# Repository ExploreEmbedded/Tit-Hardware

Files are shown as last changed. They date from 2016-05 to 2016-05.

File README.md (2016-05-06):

# Tit-Hardware
Hardware design files for Tit with Atmega328pb 

Ever wanted to have two hardware Serial Ports, two SPI, two I2C and more PWM pins on the Arduino Pro Mini? Tit has all of this, and retains the same form factor. Tit uses Atmega328PB at its core. 

Tit, is pin compatible with Arduino Pro Mini, the chip Atmega328pb is software compatible with Atmega328p. Hence all the existing code and libraries should work without any changes. Tit uses higher version of avr-gcc toolchain, we have bundled it up as a package along with additional libraries required to access the extra features. Check the setup section on installing support for the board in the Arduino IDE.

Tit

Follow the project at hackaday.io
(https://hackaday.io/project/11558-tit)
Detailed introduction and setup guide at ExploreEmbedded.com
(http://exploreembedded.com/wiki/Tit,_a_supercharged_Arduino_Pro_Mini_with_Atmega328pb)

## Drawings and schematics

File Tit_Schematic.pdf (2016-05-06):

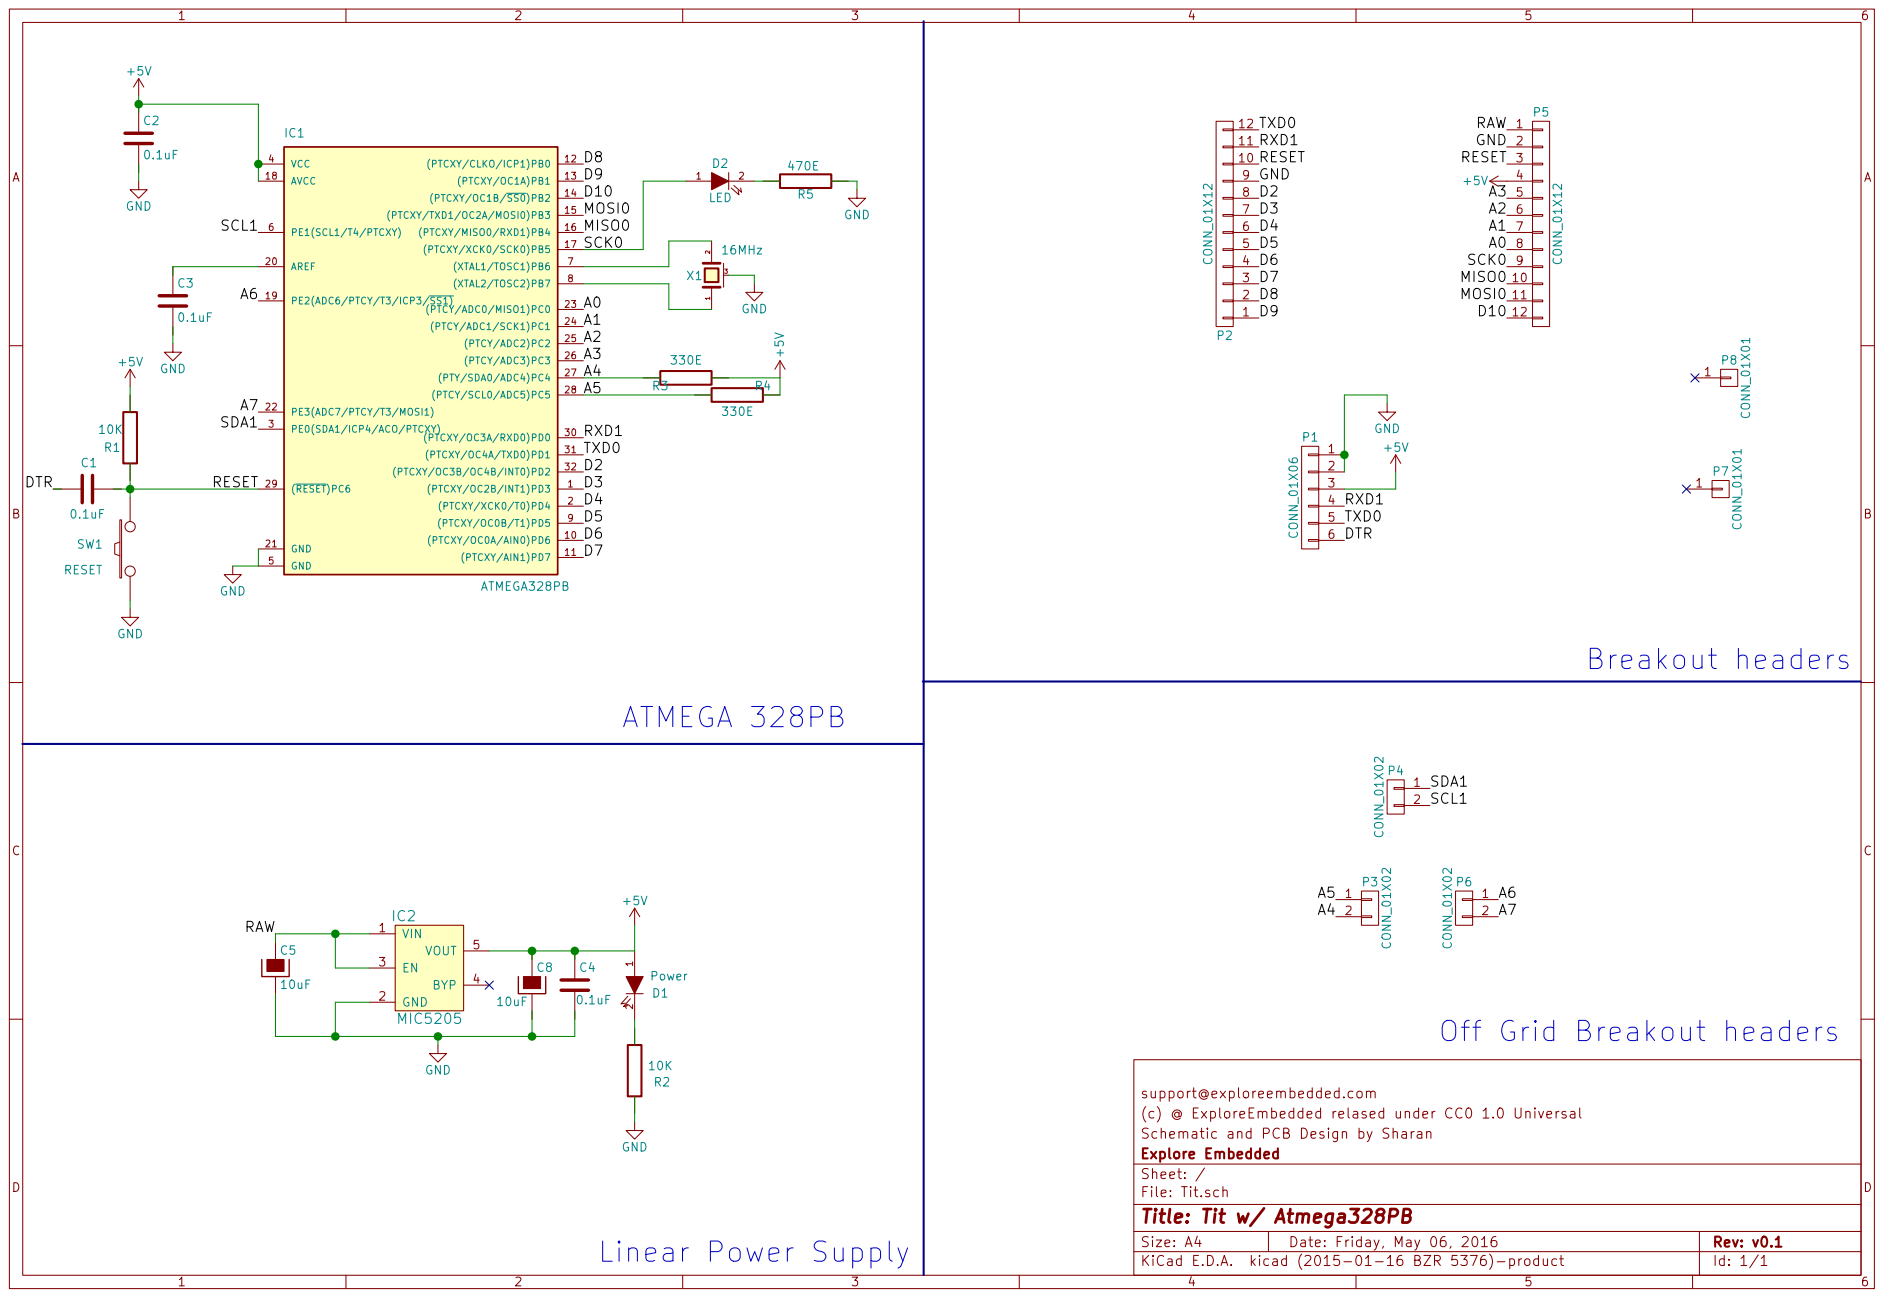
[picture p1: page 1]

support@exploreembedded.com
(c) @ ExploreEmbedded relased under CC0 1.0 Universal
Schematic and PCB Design by Sharan
File: Tit.sch Sheet: / Explore Embedded

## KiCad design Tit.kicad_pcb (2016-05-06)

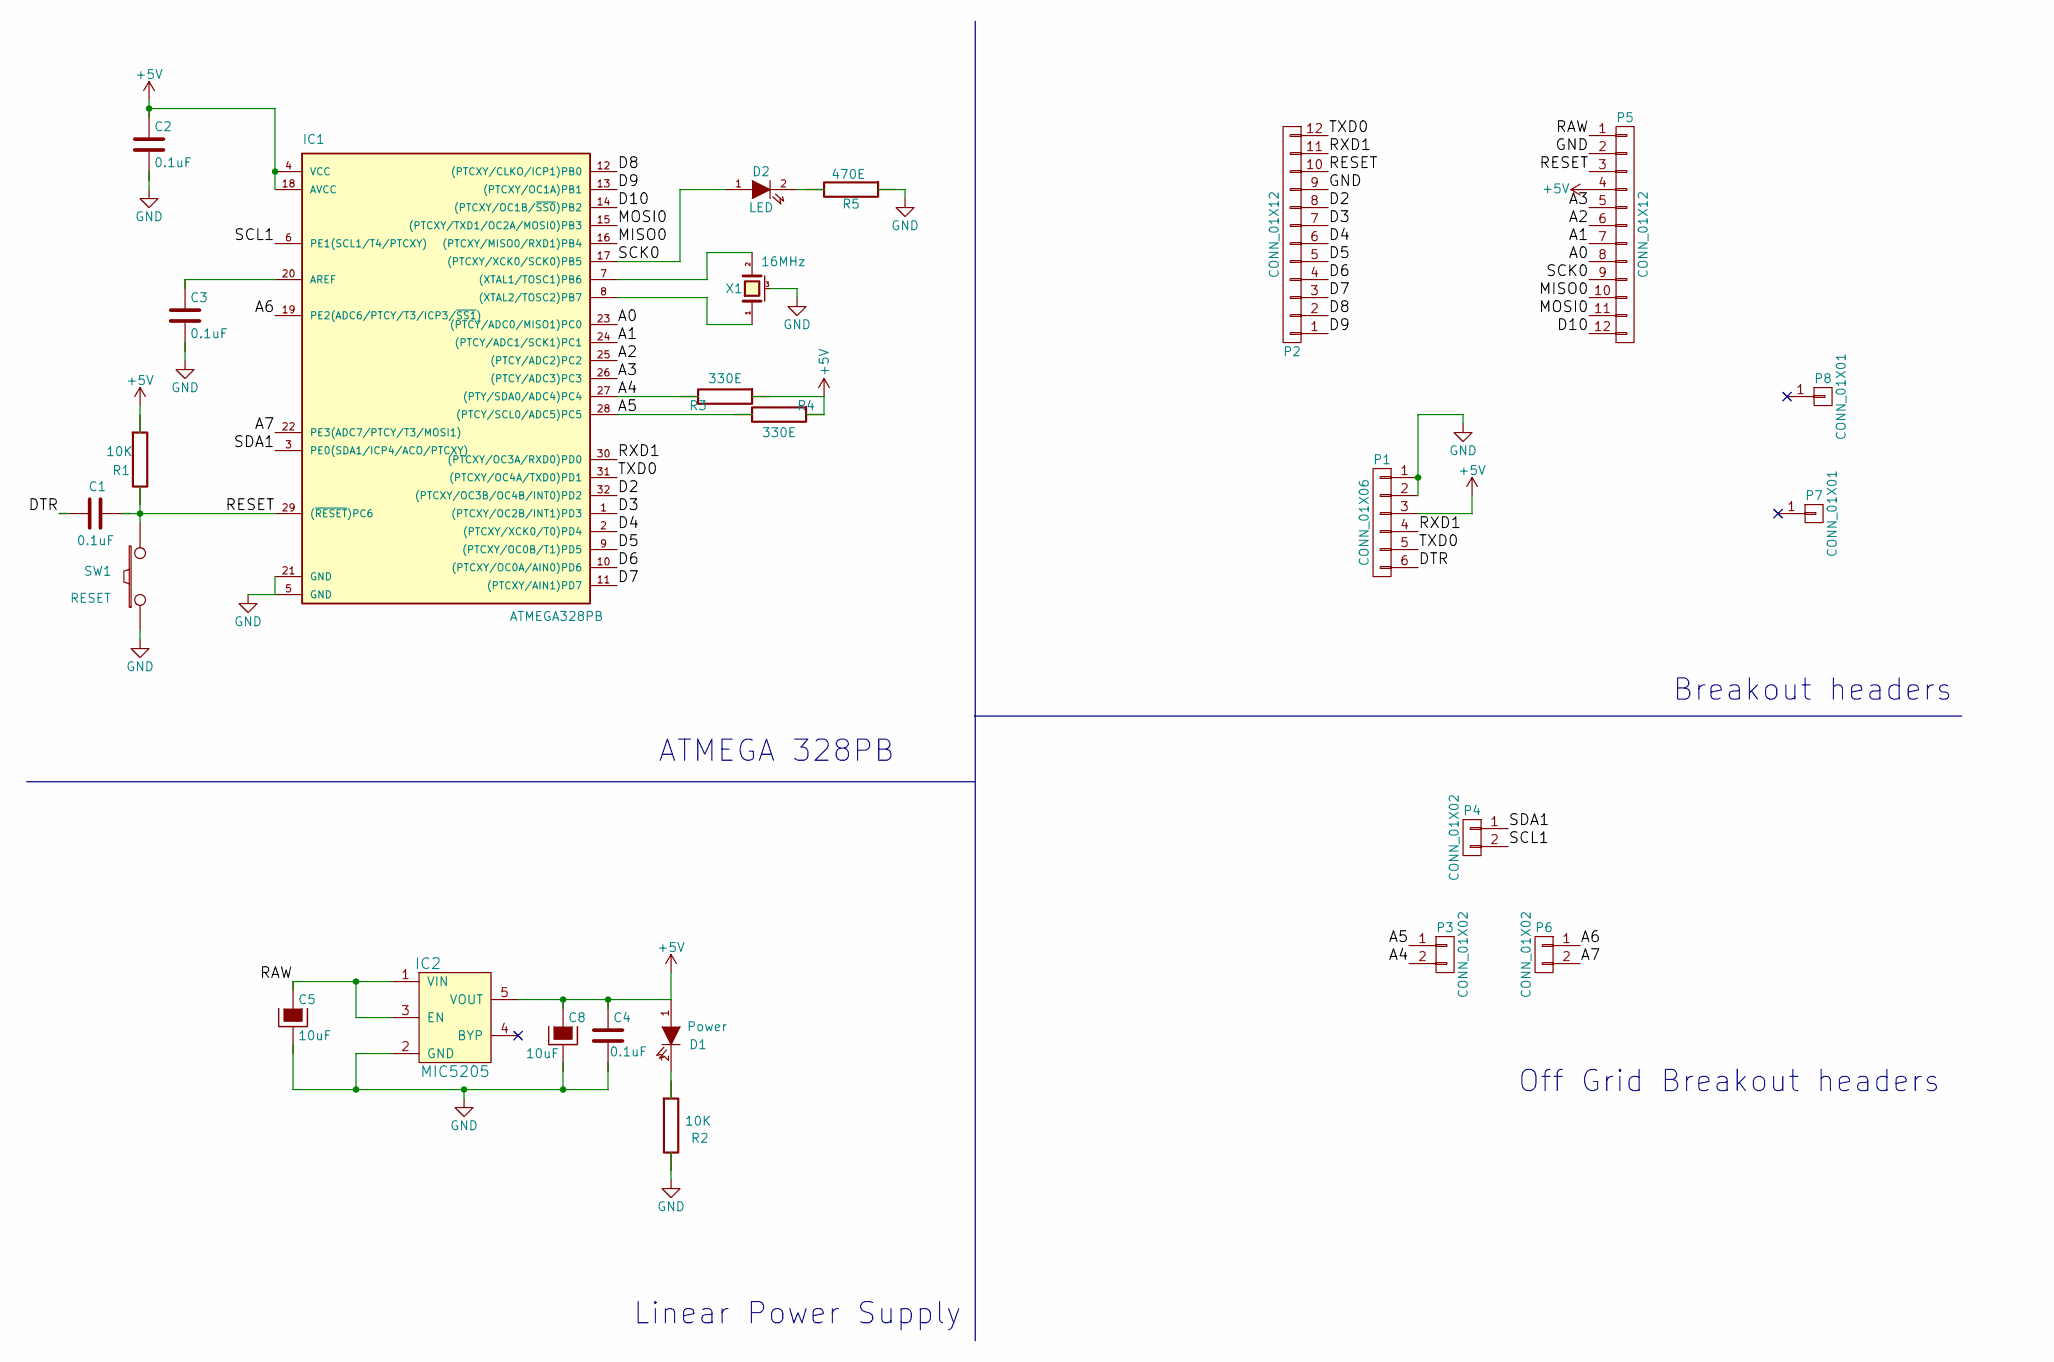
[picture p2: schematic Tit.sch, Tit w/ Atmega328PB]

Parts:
C1, C2, C3, C4: 0.1uF; C_0603
C5, C8: 10uF; C_1206
D1: Power; LED-0603
D2: LED; LED-0603
IC1: ATMEGA328PB; TQFP-32_7x7mm_Pitch0.8mm
IC2: MIC5205; SOT-23-5
P1: CONN_01X06; Pin_Header_Straight_1x06
P2, P5: CONN_01X12; Pin_Header_Straight_1x12
P3, P4, P6: CONN_01X02; Pin_Header_Straight_1x02
P7, P8: CONN_01X01
R1, R2: 10K; R_0603
R3, R4: 330E; R_0603
R5: 470E; R_0603
SW1: RESET; smd_push2
X1: 16MHz

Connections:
+5V: C2.1, C4.1, C8.1, D1.1 (A), IC1.4 (VCC), IC1.18 (AVCC), IC2.5 (VOUT), P1.3, P5.4, R1.1, R3.1, R4.1
/A0: IC1.23 ((PTCY/ADC0/MISO1)PC0), P5.8
/A1: IC1.24 ((PTCY/ADC1/SCK1)PC1), P5.7
/A2: IC1.25 ((PTCY/ADC2)PC2), P5.6
/A3: IC1.26 ((PTCY/ADC3)PC3), P5.5
/A4: IC1.27 ((PTY/SDA0/ADC4)PC4), P3.2, R3.2
/A5: IC1.28 ((PTCY/SCL0/ADC5)PC5), P3.1, R4.2
/A6: IC1.19 (PE2(ADC6/PTCY/T3/ICP3/~SS1)), P6.1
/A7: IC1.22 (PE3(ADC7/PTCY/T3/MOSI1)), P6.2
/D2: IC1.32 ((PTCXY/OC3B/OC4B/INT0)PD2), P2.8
/D3: IC1.1 ((PTCXY/OC2B/INT1)PD3), P2.7
/D4: IC1.2 ((PTCXY/XCK0/T0)PD4), P2.6
/D5: IC1.9 ((PTCXY/OC0B/T1)PD5), P2.5
/D6: IC1.10 ((PTCXY/OC0A/AIN0)PD6), P2.4
/D7: IC1.11 ((PTCXY/AIN1)PD7), P2.3
/D8: IC1.12 ((PTCXY/CLKO/ICP1)PB0), P2.2
/D9: IC1.13 ((PTCXY/OC1A)PB1), P2.1
/D10: IC1.14 ((PTCXY/OC1B/~SS0~)PB2), P5.12
/DTR: C1.2, P1.6
/MISO0: IC1.16 ((PTCXY/MISO0/RXD1)PB4), P5.10
/MOSI0: IC1.15 ((PTCXY/TXD1/OC2A/MOSI0)PB3), P5.11
/RAW: C5.1, IC2.1 (VIN), IC2.3 (EN), P5.1
/RESET: C1.1, IC1.29 ((~RESET~)PC6), P2.10, P5.3, R1.2, SW1.2
/RXD1: IC1.30 ((PTCXY/OC3A/RXD0)PD0), P1.4, P2.11
/SCK0: D2.1 (A), IC1.17 ((PTCXY/XCK0/SCK0)PB5), P5.9
/SCL1: IC1.6 (PE1(SCL1/T4/PTCXY)), P4.2
/SDA1: IC1.3 (PE0(SDA1/ICP4/ACO/PTCXY)), P4.1
/TXD0: IC1.31 ((PTCXY/OC4A/TXD0)PD1), P1.5, P2.12
GND: C2.2, C3.2, C4.2, C5.2, C8.2, IC1.5 (GND), IC1.21 (GND), IC2.2 (GND), P1.1, P1.2, P2.9, P5.2, R2.2, R5.1, SW1.1, X1.3 (case)
unnamed: C3.1, IC1.20 (AREF)
unnamed: D1.2 (K), R2.1
unnamed: D2.2 (K), R5.2
unnamed: IC1.7 ((XTAL1/TOSC1)PB6), X1.2
unnamed: IC1.8 ((XTAL2/TOSC2)PB7), X1.1

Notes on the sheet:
Off Grid Breakout headers
Breakout headers
Linear Power Supply
ATMEGA 328PB

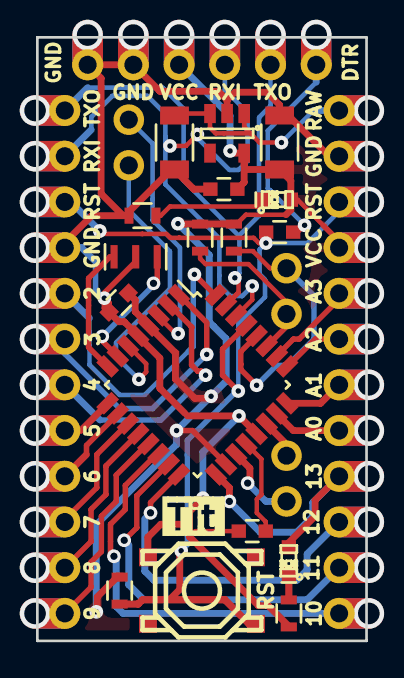
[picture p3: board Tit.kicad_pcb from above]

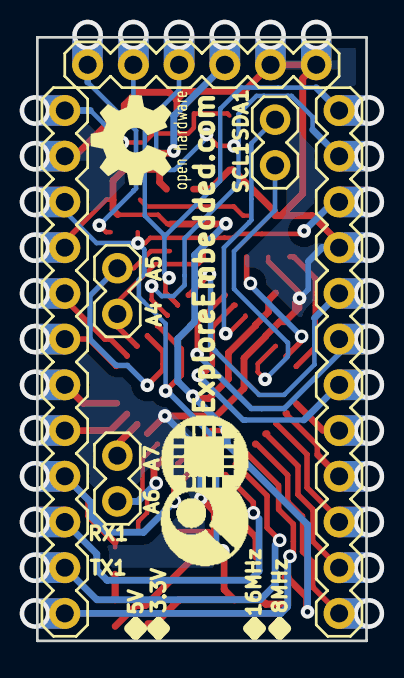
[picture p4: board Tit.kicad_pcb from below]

Board: 2 copper layers, 18.3 x 33.5 mm, 26 parts (2 on the bottom side), 34 nets.

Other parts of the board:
LOGO: LOGO (4)
